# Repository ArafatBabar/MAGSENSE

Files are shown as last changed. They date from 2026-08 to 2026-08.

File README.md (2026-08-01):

# MagSense

<p align="center">
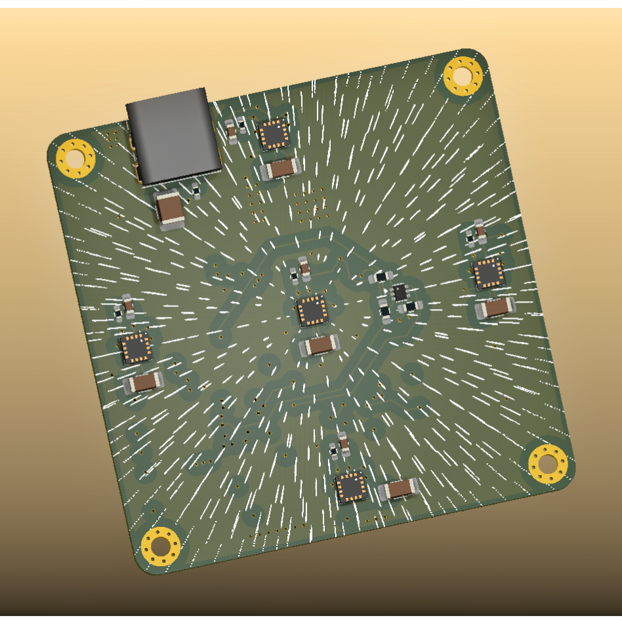
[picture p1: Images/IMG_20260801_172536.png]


</p>

<p align="center">

**An open-source multi-sensor magnetic field imaging platform.**

</p>

---

## Overview

MagSense is designed to measure the spatial distribution of magnetic fields rather than a single magnetic field value.

Instead of relying on one sensor, MagSense uses a synchronized array of five high-resolution magnetometers to capture magnetic field information at multiple locations simultaneously. This enables magnetic field visualization, gradient estimation and future magnetic source localization algorithms.

The project is being developed as an open-source hardware platform intended for research, education and experimentation.

---

# What's New in Rev.2

Rev.2 is a complete hardware redesign focused on improving signal integrity, reliability and manufacturability.

### Hardware Changes

- Migrated to STM32G431 with native USB support
- Redesigned 4-layer PCB architecture
- Added USB Type-C interface with ESD protection
- Implemented automatic power source selection
- Integrated CAN transceiver for future industrial communication
- Added Qwiic expansion connector
- Added onboard temperature sensor for future compensation
- Added RGB status indicator
- Improved debugging interface and test points
- Optimized routing for the magnetometer array

---

# Hardware

| Component | Device |
|---|---|
| MCU | STM32G431CBT6 |
| Magnetometers | 5 × MMC5983MA |
| Temperature Sensor | TMP112 |
| USB | Native USB FS |
| Power MUX | TPS2115A |
| LDO | TPS7A0233 |
| CAN | TLT9251 |
| Expansion | Qwiic |

---

# Sensor Geometry

```
        Top

Left   Center   Right

      Bottom
```

Each outer sensor is positioned 20 mm from the center.

All sensors maintain identical orientation to simplify calibration and gradient calculations.

---

# Why Five Sensors?

Most low-cost magnetic sensing platforms use a single sensor and can only report the magnetic field at one location.

MagSense measures the magnetic field at five synchronized points, allowing future implementation of:

- Magnetic field interpolation
- Gradient estimation
- Vector field visualization
- Magnetic source localization
- Multi-point magnetic field analysis

---

# Repository

```
Hardware/
Firmware/
Software/
Documentation/
```

---

# Current Status

## Hardware

- [x] Architecture
- [x] Schematic
- [x] PCB Layout (Rev.2)
- [ ] PCB Fabrication
- [ ] Bring-up
- [ ] Validation

---

## Next Steps

- Prototype manufacturing
- Hardware validation
- Firmware development
- Sensor calibration
- Desktop visualization software

---

## License

Hardware: CERN-OHL-S v2

Firmware & Software: MIT

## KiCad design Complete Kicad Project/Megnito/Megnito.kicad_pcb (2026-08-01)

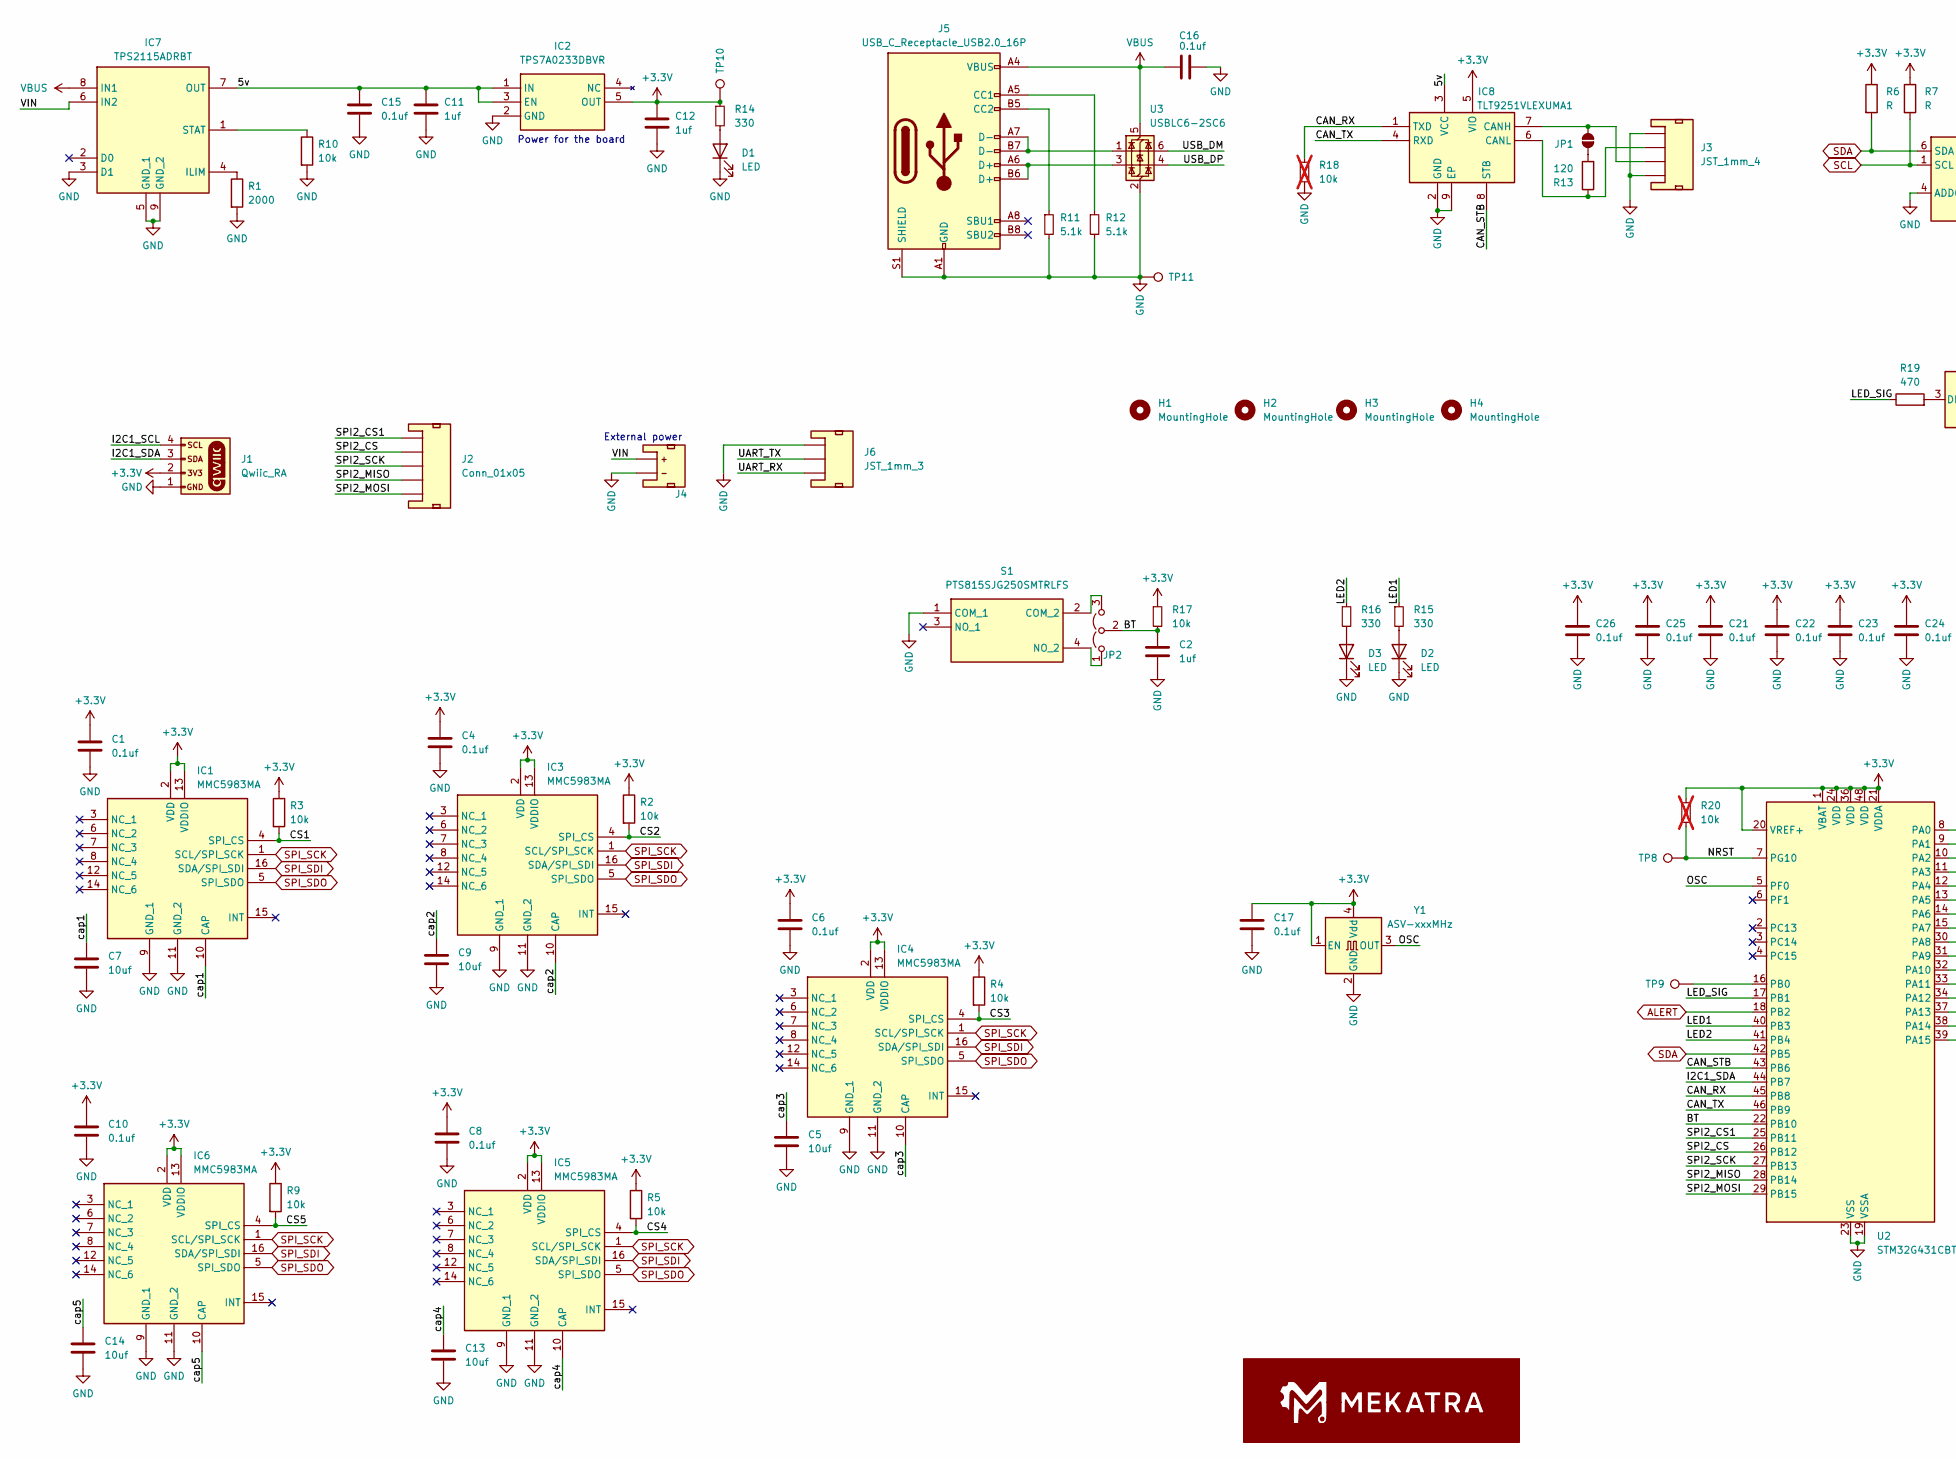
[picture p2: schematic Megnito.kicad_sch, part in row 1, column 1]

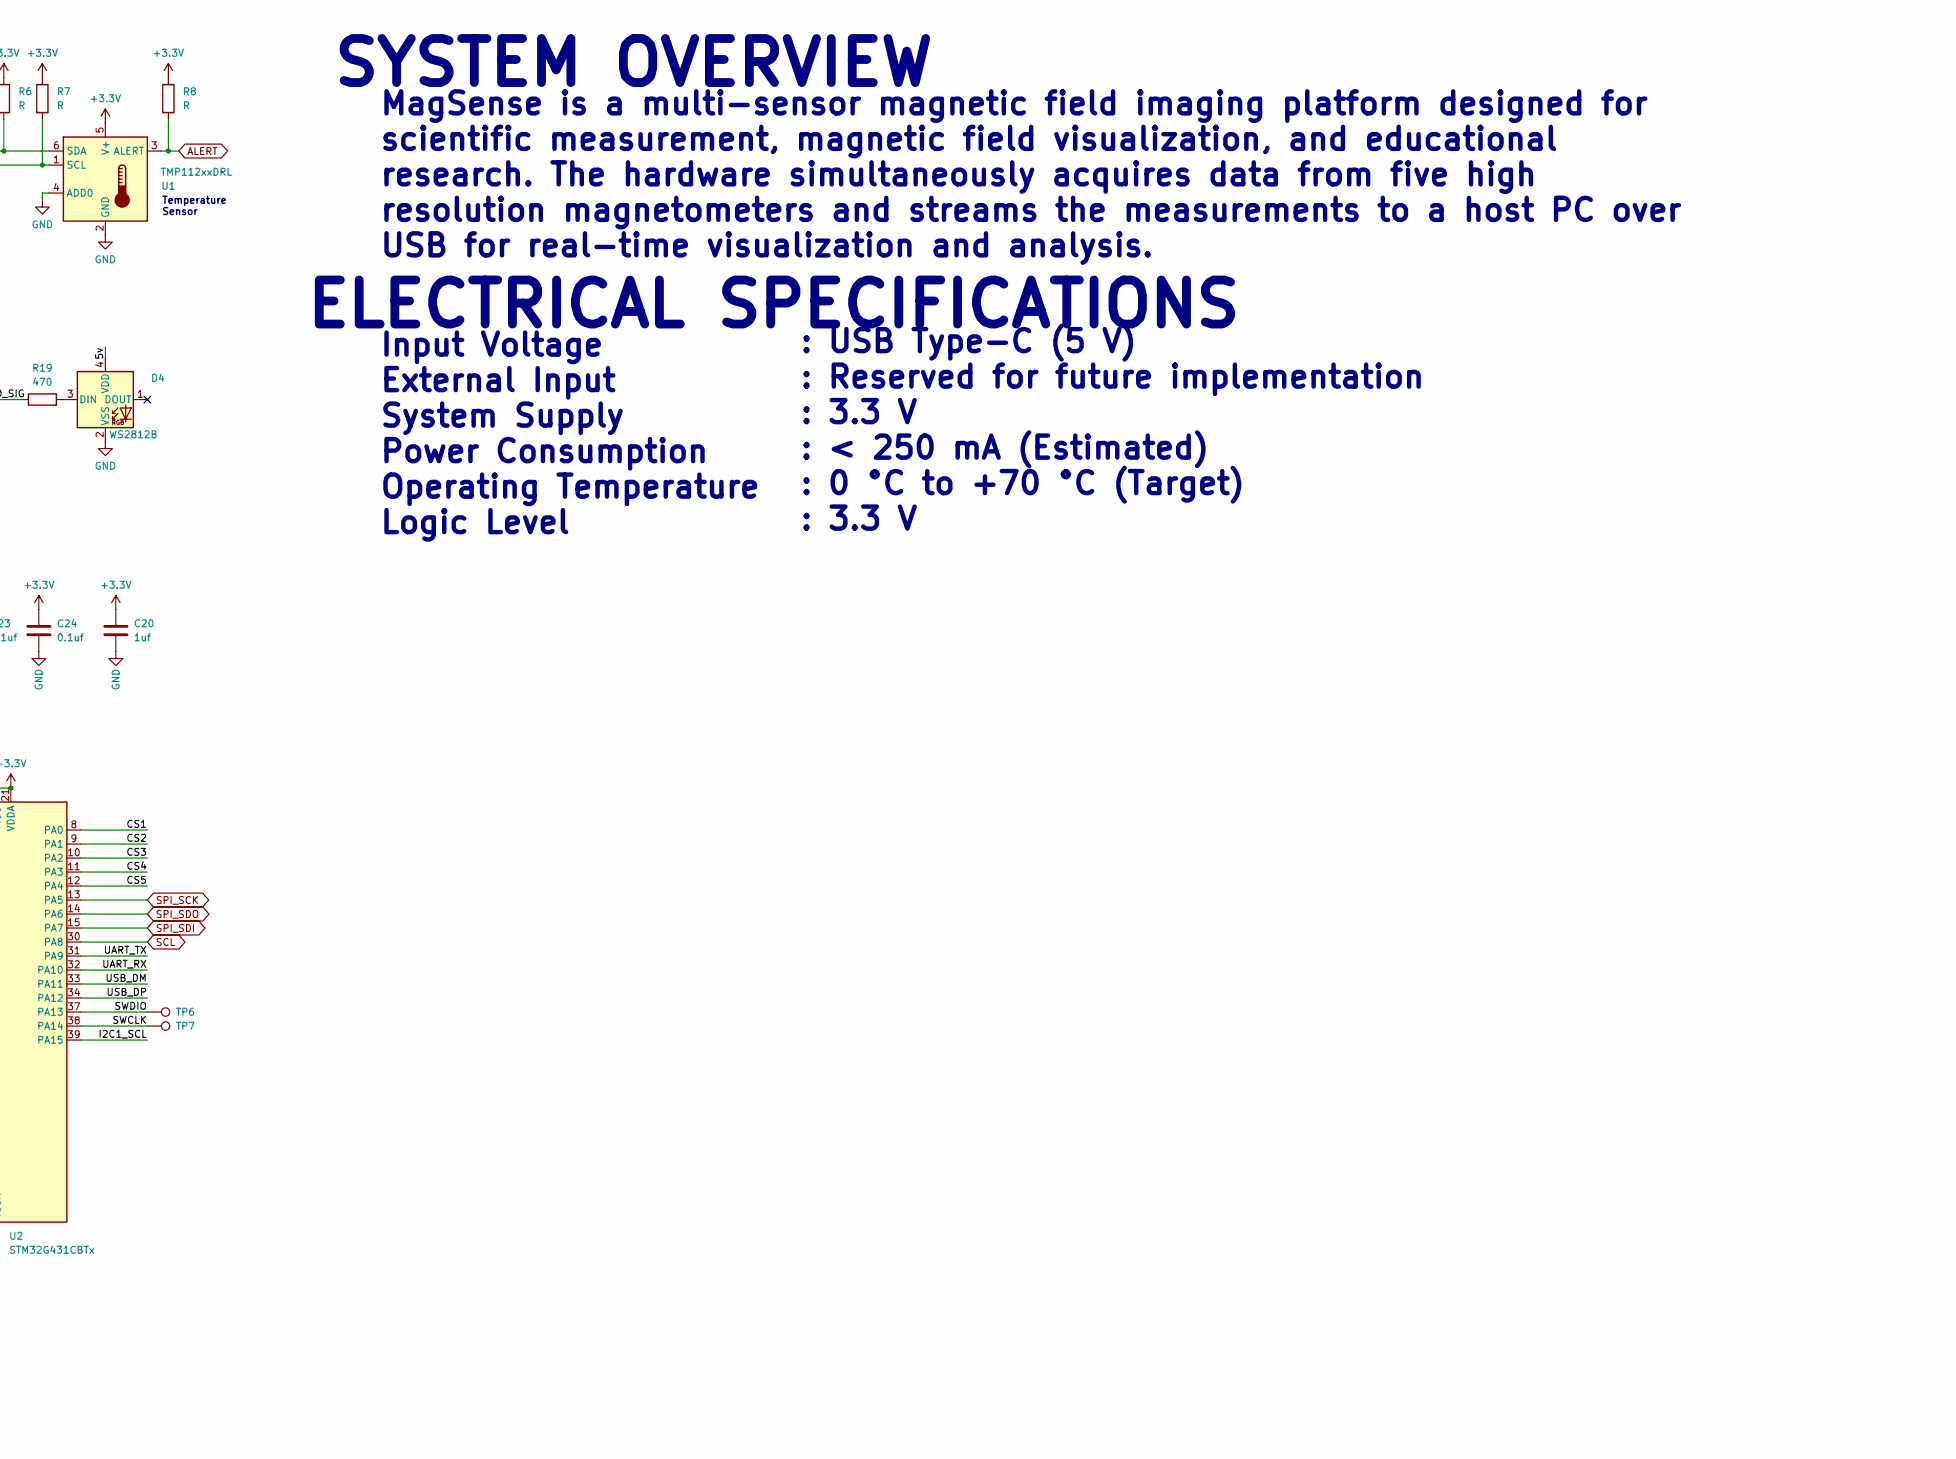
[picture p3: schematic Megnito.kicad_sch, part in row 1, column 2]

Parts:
C1, C4, C6, C8, C10: 0.1uf; C_0603_1608Metric_Pad1.08x0.95mm_HandSolder
C2: 1uf; C_0603_1608Metric_Pad1.08x0.95mm_HandSolder
C5, C7, C9, C13, C14: 10uf; C_1206_3216Metric_Pad1.33x1.80mm_HandSolder
C11, C12, C20: 1uf; C_1210_3225Metric_Pad1.33x2.70mm_HandSolder
C15, C16, C17: 0.1uf; C_1210_3225Metric_Pad1.33x2.70mm_HandSolder
C21, C22, C23, C24, C25, C26: 0.1uf; C_0402_1005Metric_Pad0.74x0.62mm_HandSolder
D1, D2, D3: LED; LED_0402_1005Metric_Pad0.77x0.64mm_HandSolder
D4: WS2812B; LED_WS2812B-2020_PLCC4_2.0x2.0mm
H1, H2, H3, H4: MountingHole; MountingHole_2.2mm_M2_Pad_Via
IC1, IC3, IC4, IC5, IC6: MMC5983MA; Manufacturer_Part_Number MMC5983MA; Mouser Part Number 438-MMC5983MA
IC2: TPS7A0233DBVR; SOT95P280X145-5N; Manufacturer_Part_Number TPS7A0233DBVR; Mouser Part Number 595-TPS7A0233DBVR
IC7: TPS2115ADRBT; SON65P300X300X100-9N-D; Manufacturer_Part_Number TPS2115ADRBT; Mouser Part Number 595-TPS2115ADRBT
IC8: TLT9251VLEXUMA1; SON65P300X300X110-9N; Manufacturer_Part_Number TLT9251VLEXUMA1; Mouser Part Number 726-TLT9251VLEXUMA1
J1: Qwiic_RA; JST_1x04_P1.0mm_Horizontal_SMD
J2: Conn_01x05; JST_1x05_P1.0mm_Horizontal_SMD
J3: JST_1mm_4; JST_1x04_P1.0mm_Horizontal_SMD
J4: JST_2mm_LiPo; JST_1x02_P2.0mm_Horizontal_SMD
J5: USB_C_Receptacle_USB2.0_16P; USB_C_Receptacle_GCT_USB4085
J6: JST_1mm_3; JST_1x03_P1.0mm_Horizontal_SMD
JP1: Jumper_2_NO
JP2: Jumper_3_Open; Jumper_3_NO_NoSilk
R1: 2000; R_0402_1005Metric_Pad0.72x0.64mm_HandSolder
R2, R3, R4, R5, R9, R10, R17: 10k; R_0402_1005Metric_Pad0.72x0.64mm_HandSolder
R6, R7, R8: R; R_0603_1608Metric_Pad0.98x0.95mm_HandSolder
R11, R12: 5.1k; R_0402_1005Metric_Pad0.72x0.64mm_HandSolder
R13: 120; R_2512_6332Metric_Pad1.40x3.35mm_HandSolder
R14, R15, R16: 330; R_0402_1005Metric_Pad0.72x0.64mm_HandSolder
R18, R20: 10k; R_0402_1005Metric_Pad0.72x0.64mm_HandSolder; not fitted
R19: 470; R_0603_1608Metric_Pad0.98x0.95mm_HandSolder
S1: PTS815SJG250SMTRLFS; Manufacturer_Part_Number PTS815SJG250SMTRLFS
TP6: SWDIO; TestPoint_Pad_D1.0mm
TP7: SWCLK; TestPoint_Pad_D1.0mm
TP8: NRST; TestPoint_Pad_D1.0mm
TP9: PB0; TestPoint_Pad_D1.0mm
TP10: 3V3; TestPoint_Pad_D1.0mm
TP11: GND; TestPoint_Pad_D1.0mm
U1: TMP112xxDRL; SOT-563
U2: STM32G431CBTx; LQFP-48_7x7mm_P0.5mm
U3: USBLC6-2SC6; SOT-23-6
Y1: ASV-xxxMHz; Oscillator_SMD_Abracon_ASV-4Pin_7.0x5.1mm

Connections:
+3.3V: C1.1, C4.1, C6.1, C8.1, C10.1, C12.1, C17.1, C20.1, C21.1, C22.1, C23.1, C24.1, C25.1, C26.1, IC1.2 (VDD), IC1.13 (VDDIO), IC2.5 (OUT), IC3.2 (VDD), IC3.13 (VDDIO), IC4.2 (VDD), IC4.13 (VDDIO), IC5.2 (VDD), IC5.13 (VDDIO), IC6.2 (VDD), IC6.13 (VDDIO), IC8.5 (VIO), J1.2, R2.1, R3.1, R4.1, R5.1, R6.1, R7.1, R8.1, R9.1, R14.1, R17.1, R20.1, TP10.1, U1.5 (V+), U2.1 (VBAT), U2.20 (VREF+), U2.21 (VDDA), U2.24 (VDD), U2.36 (VDD), U2.48 (VDD), Y1.1 (EN), Y1.4 (Vdd)
/5v: C11.1, C15.1, D4.4 (VDD), IC2.1 (IN), IC2.3 (EN), IC7.7 (OUT), IC8.3 (VCC)
/BT: C2.1, JP2.2 (C), R17.2, U2.22 (PB10)
/CAN_RX: IC8.1 (TXD), R18.1, U2.45 (PB8)
/CAN_STB: IC8.8 (STB), U2.43 (PB6)
/CAN_TX: IC8.4 (RXD), U2.46 (PB9)
/CS1: IC1.4 (SPI_CS), R3.2, U2.8 (PA0)
/CS2: IC3.4 (SPI_CS), R2.2, U2.9 (PA1)
/CS3: IC4.4 (SPI_CS), R4.2, U2.10 (PA2)
/CS4: IC5.4 (SPI_CS), R5.2, U2.11 (PA3)
/CS5: IC6.4 (SPI_CS), R9.2, U2.12 (PA4)
/I2C1_SCL: J1.4, U2.39 (PA15)
/I2C1_SDA: J1.3, U2.44 (PB7)
/LED1: R15.1, U2.40 (PB3)
/LED2: R16.1, U2.41 (PB4)
/LED_SIG: R19.1, U2.17 (PB1)
/NRST: R20.2, TP8.1, U2.7 (PG10)
/OSC: U2.5 (PF0), Y1.3 (OUT)
/SPI2_CS: J2.2, U2.26 (PB12)
/SPI2_CS1: J2.1, U2.25 (PB11)
/SPI2_MISO: J2.4, U2.28 (PB14)
/SPI2_MOSI: J2.5, U2.29 (PB15)
/SPI2_SCK: J2.3, U2.27 (PB13)
/SWCLK: TP7.1, U2.38 (PA14)
/SWDIO: TP6.1, U2.37 (PA13)
/UART_RX: J6.3, U2.32 (PA10)
/UART_TX: J6.2, U2.31 (PA9)
/USB_DM: U2.33 (PA11), U3.6 (I/O1)
/USB_DP: U2.34 (PA12), U3.4 (I/O2)
/VIN: IC7.6 (IN2), J4.2 (+)
/cap1: C7.1, IC1.10 (CAP)
/cap2: C9.1, IC3.10 (CAP)
/cap3: C5.1, IC4.10 (CAP)
/cap4: C13.1, IC5.10 (CAP)
/cap5: C14.1, IC6.10 (CAP)
ALERT: R8.2, U1.3 (ALERT), U2.18 (PB2)
GND: C1.2, C2.2, C4.2, C5.2, C6.2, C7.2, C8.2, C9.2, C10.2, C11.2, C12.2, C13.2, C14.2, C15.2, C16.2, C17.2, C20.2, C21.2, C22.2, C23.2, C24.2, C25.2, C26.2, D1.1 (K), D2.1 (K), D3.1 (K), D4.2 (VSS), IC1.9 (GND_1), IC1.11 (GND_2), IC2.2 (GND), IC3.9 (GND_1), IC3.11 (GND_2), IC4.9 (GND_1), IC4.11 (GND_2), IC5.9 (GND_1), IC5.11 (GND_2), IC6.9 (GND_1), IC6.11 (GND_2), IC7.3 (D1), IC7.5 (GND_1), IC7.9 (GND_2), IC8.2 (GND), IC8.9 (EP), J1.1, J1.NC1 (NC), J1.NC2 (NC), J2.NC1, J2.NC2, J3.1, J3.4, J4.1 (-), J5.A1 (GND), J5.A12 (GND), J5.B1 (GND), J5.B12 (GND), J5.S1 (SHIELD), J6.1, J6.NC1, J6.NC2, R1.2, R10.2, R11.2, R12.2, R18.2, S1.1 (COM_1), TP11.1, U1.2 (GND), U1.4 (ADD0), U2.19 (VSSA), U2.23 (VSS), U2.35 (VSS), U2.47 (VSS), U3.2 (GND), Y1.2 (GND)
unnamed: D1.2 (A), R14.2
unnamed: D2.2 (A), R15.2
unnamed: D3.2 (A), R16.2
unnamed: D4.3 (DIN), R19.2
unnamed: IC7.4 (ILIM), R1.1
unnamed: IC7.1 (STAT), R10.1
unnamed: IC8.7 (CANH), J3.3, JP1.1 (A)
unnamed: IC8.6 (CANL), J3.2, R13.1
unnamed: J5.A5 (CC1), R12.1
unnamed: J5.B5 (CC2), R11.1
unnamed: J5.A6 (D+), J5.B6 (D+), U3.3 (I/O2)
unnamed: J5.A7 (D-), J5.B7 (D-), U3.1 (I/O1)
unnamed: JP1.2 (B), R13.2
unnamed: JP2.1 (A), S1.4 (NO_2)
unnamed: JP2.3 (B), S1.2 (COM_2)
unnamed: TP9.1, U2.16 (PB0)
SCL: R7.2, U1.1 (SCL), U2.30 (PA8)
SDA: R6.2, U1.6 (SDA), U2.42 (PB5)
SPI_SCK: IC1.1 (SCL/SPI_SCK), IC3.1 (SCL/SPI_SCK), IC4.1 (SCL/SPI_SCK), IC5.1 (SCL/SPI_SCK), IC6.1 (SCL/SPI_SCK), U2.13 (PA5)
SPI_SDI: IC1.16 (SDA/SPI_SDI), IC3.16 (SDA/SPI_SDI), IC4.16 (SDA/SPI_SDI), IC5.16 (SDA/SPI_SDI), IC6.16 (SDA/SPI_SDI), U2.15 (PA7)
SPI_SDO: IC1.5 (SPI_SDO), IC3.5 (SPI_SDO), IC4.5 (SPI_SDO), IC5.5 (SPI_SDO), IC6.5 (SPI_SDO), U2.14 (PA6)
VBUS: C16.1, IC7.8 (IN1), J5.A4 (VBUS), J5.A9 (VBUS), J5.B4 (VBUS), J5.B9 (VBUS), U3.5 (VBUS)

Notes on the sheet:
Power for the board
: USB Type-C (5 V) : Reserved for future implementation : 3.3 V : < 250 mA (Estimated) : 0 °C to +70 °C (Target) : 3.3 V
ELECTRICAL SPECIFICATIONS
SYSTEM OVERVIEW
MagSense is a multi-sensor magnetic field imaging platform designed for scientific measurement, magnetic field visualization, and educational research. The hardware simultaneously acquires data from five high resolution magnetometers and streams the measurements to a host PC over USB for real-time 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
Input Voltage External Input System Supply Power Consumption Operating Temperature Logic Level
External power
Temperature Sensor

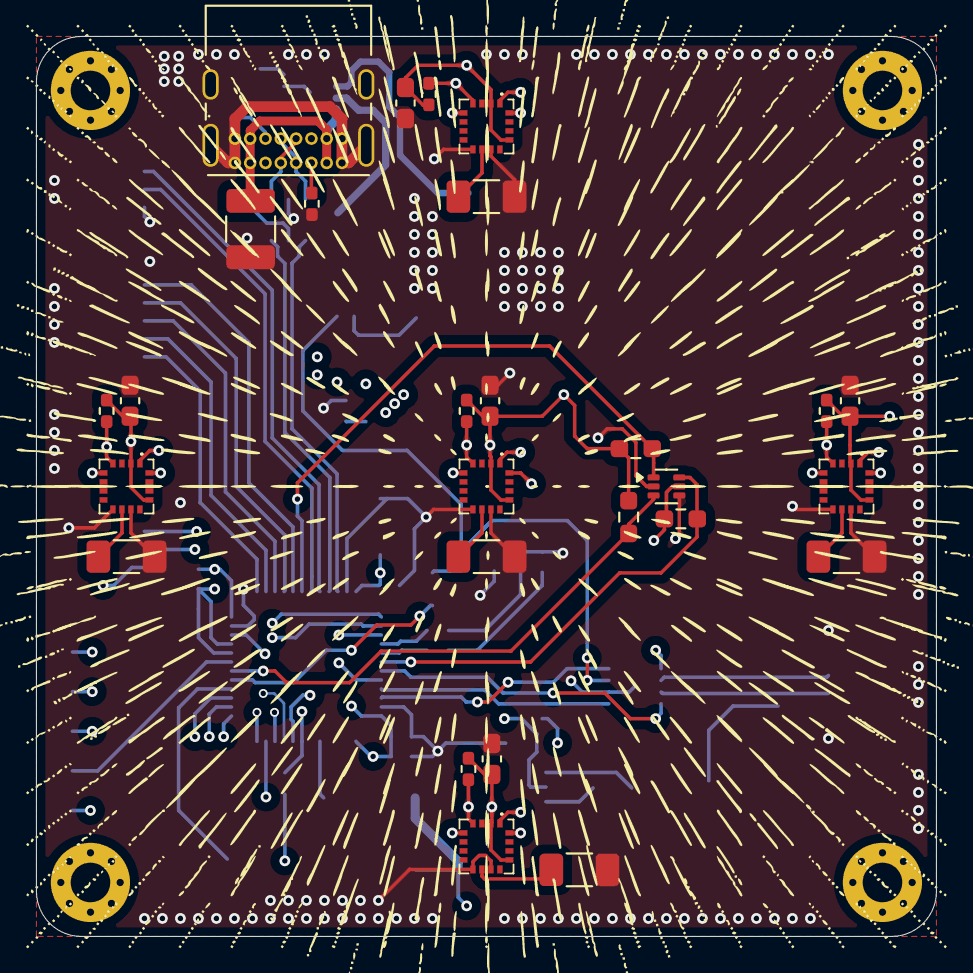
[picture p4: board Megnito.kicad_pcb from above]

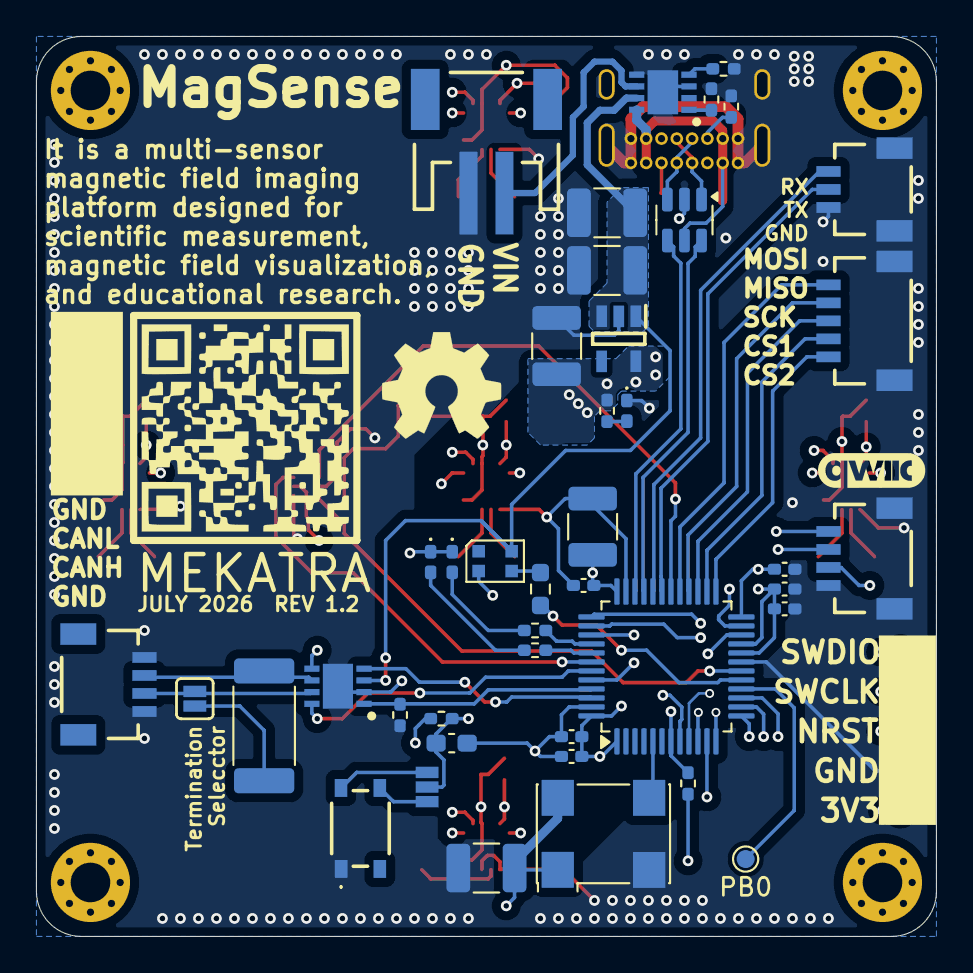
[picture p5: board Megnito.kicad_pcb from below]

Board: 6 copper layers, 50.0 x 50.0 mm, 78 parts (47 on the bottom side), 59 nets.

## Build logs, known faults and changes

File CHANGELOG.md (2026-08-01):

# Changelog

## Rev.2

### Added

- STM32G431 microcontroller
- Five-sensor MMC5983MA array
- Native USB-C interface
- CAN interface
- Qwiic connector
- WS2812 RGB status LED
- Automatic power-path management

### Improved

- Complete PCB redesign
- 4-layer stack-up
- Power integrity
- Signal integrity
- Manufacturability

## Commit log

2026-08-01 uploaded schematic
2026-08-01 Revise README with project overview and details
    Updated project overview and detailed system architecture, including hardware and software implementation. Added planned features and current status.
2026-08-01 uploaded renders of the PCB
2026-08-01 complete hardware uploaded
    [Megnito.kicad_pcb, Megnito.kicad_sch]
